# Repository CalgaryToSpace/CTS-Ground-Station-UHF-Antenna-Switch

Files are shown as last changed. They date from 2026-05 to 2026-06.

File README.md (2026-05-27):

# CTS-Ground-Station-UHF-Antenna-Switch

PCB and firmware for a ground station UHF antenna switch (between high-power uplink and low-noise downlink, via a single antenna).

This is a high-power UHF antenna switch PCB (for separate RX/TX paths), controlled with automatic TX sensing.

## Status

Rev 1 PCB works and is deployed at the CalgaryToSpace ground station as of 2026-05-26.

Rev 2 PCB is under development, though it is only a small incremental improvement over Rev 1. Main goal with Rev 2 is to improve the isolation performance.

## Render

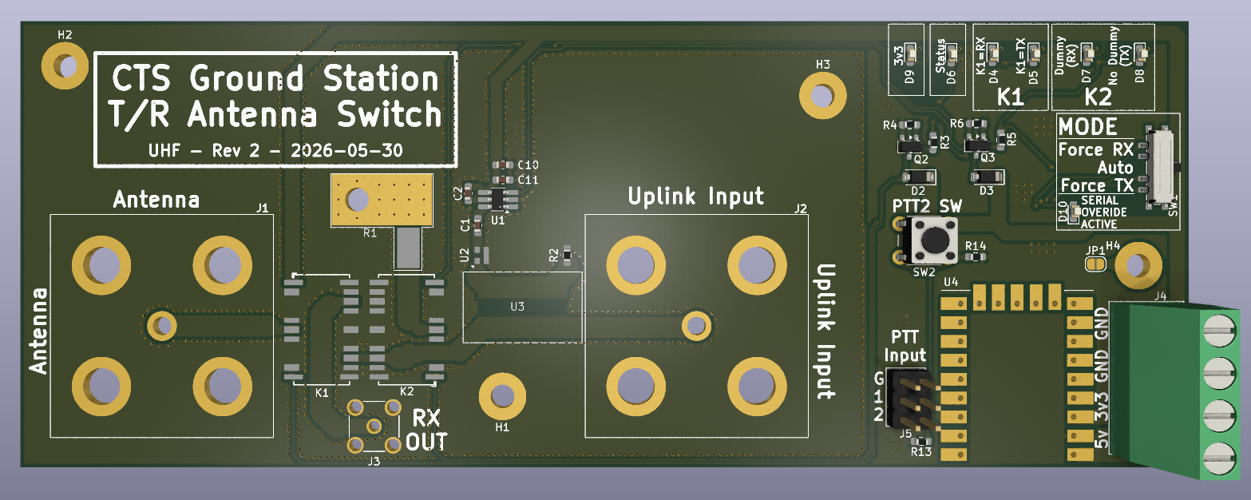
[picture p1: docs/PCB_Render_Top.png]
PCB Top Render


See the Releases for schematics, gerbers, and BOM.

## Features

* High Power: Supports TX power of >45 dBm (>30 W)
* Low insertion loss
* Automatic carrier sensing on the TX line (easy to deploy)
* Shunt-to-GND: Avoids damage to the transmitter by avoiding reflecting any power back on the TX port, in case of switching latency or failure. Dissipates as heat through a dummy load.
* LED indicators.
* Uses RF relays for switching. Simple design and minimal power supply requirements, compared to PIN Diode alternative approach.
* Logs via USB serial interface.
* Optional slide switch to override control modes.
* Optional control via USB serial interface overrides.

## Key Components

* RF Relay: `1462051-1` (`HF3-1` with 3V control, aka `HF3-51`)
* Dummy Load Resistor: `I100N50X4B`
* RF Attenuator (10 dB): `PAT1220-C-10DB-T5`
* RF Detector: `LTC5507ES6`
* Microcontroller: RP2040-Zero PCB

## License

* **Hardware Parts:** CERN Open Hardware Licence Version 2 - Permissive
* **Firmware:** Apache 2.0 License

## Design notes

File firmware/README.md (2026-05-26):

# CTS UHF RX/TX Switch Firmware

This firmware runs on the RP2040-Zero microcontroller board on the PCB.

## Building (Linux and macOS)

To build the firmware, follow these steps:

```bash
# Optionally, specify the Pico SDK path to your cloned Pico SDK (not recommended):
git clone https://github.com/raspberrypi/pico-sdk.git ~/pico-sdk
export PICO_SDK_PATH=~/pico-sdk

# If you skip the steps above (recommended to skip), cmake will automatically clone the Pico SDK.
cd firmware  # Navigate to the firmware directory of the repo.
mkdir build && cd build
cmake ..
make -j
```

## Flashing

1. Hold **BOOTSEL** on the RP2040-Zero while plugging it in. Or, hold **BOOTSEL** and press the reset button.
2. See that it mounts as a USB drive.
3. Drag `build/cts_uhf_rxtx_switch.uf2` onto it.
4. It'll reboot and run.

## Monitor via USB Serial

Open the USB serial port at 115200 baud:

```bash
# Linux
screen /dev/ttyACM0 115200

# macOS
screen /dev/tty.usbmodem* 115200
```

Press keys 0, 1, 2, 3 to set log level (0 = default and least verbose, 3 = most verbose).

To kill `screen`, press `Ctrl+A`, then nothing will appear to happen, then `k`, then `y` when prompted.

## IDE Support

After building, enable IDE support by creating a symbolic link to `compile_commands.json` in the build directory:

```bash
cd firmware
ln -s build/compile_commands.json compile_commands.json
```

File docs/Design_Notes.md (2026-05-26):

# Design Notes

## Checklist

* Unbroken ground plane under all RF.

## Dummy Load

* Use thin-film chip resistors. Standard thick-film resistors have too much parasitic inductance at UHF.
* Add a heatsink to the bottom of the board, potentially.
* Intended to operate only in small bursts, so thermal dissipation isn't as big of a deal.

### Test Notes

* SWR should be < 1.1:1 at 436 MHz for a good dummy load.
* Check for resonances. A peak in SWR somewhere means parasitic inductance or capacitance in the layout.

## Detector Chain

Input TX -> RF Coupler with PCB Traces -> Attenuator -> RF Detector -> Logic

* Input TX (rate up to 100W = 50 dBm for this assessment)
* RF Coupler with PCB Traces (50 dBm - 40 dB = 10 dBm)
    * Raw PCB traces running parallel to each other on the PCB act as an RF coupler.
    * Target -40 dB power transfer in coupler.
    * See the design doc for this coupler section specifically for more details.
* Attenuator (10 dB)
    * Part: PAT1220-C-10DB
* LTC5507 RF Detector
    * Supports -34 dBm to 14 dBm input.
    * At 50 dBm input, output power is approximately 10 dBm.
    * At 100 mW (20 dBm), output power is approximately -30 dBm. Should be possible to test with even just an SDR directly.

### Alternative Plan

<details summary="Click to expand">

Input TX -> RF Directional Coupler -> Attenuator -> RF Detector -> Logic

* Input TX (rate up to 100W = 50 dBm for this assessment)
* RF Directional Coupler (50 dBm down - 33 dB = 17 dBm)
    * Part: X4C09F1-30S
* Attenuator (10 dB)
    * Part: PAT1220-C-10DB
* LTC5507 RF Detector
    * Supports -34 dBm to 14 dBm input.

</details>

## RF Connectors

* SMA Connectors are [rated to >100W](https://electronics.stackexchange.com/a/74929), under ideal conditions and construction.
* N-Type connectors are better, where feasible. A [PCB-mount N-Type connector](https://www.mouser.ca/ProductDetail/Amphenol-RF/172234) is a good option.

* Alternatives considered:
    * https://www.digikey.ca/en/products/detail/huber-suhner-inc/92-N-50-0-6-111-NY/16806991
    * https://www.digikey.ca/en/products/detail/amphenol-rf/83-1R/80248

## Footprints

* RP2040-Zero footprint copied from https://github.com/dj505/RP2040-Zero-KiCAD (CERN Open Hardware License v2 - Permissive).

## Relay Switching Logic

* 2 relays.
    * K1: Picks between RX and TX.
    * K2: Adds a dummy loads to the TX line when in RX mode.

* Actions:
    * Nominally: K1 is in RX mode, and K2 is in Dummy mode.
    * When sense is detected: K1 switch to TX mode. Delay. K2 to TX mode.
    * When sense is done: K2 to Dummy mode. Delay. K1 to RX mode.

## Stackup, RF PCB Impedance

By using JLCPCB's default 1.6mm FR4 2-layer board, we can get a 50 ohm impedance with a large trace width, which is helpful for managing the high current.

For nearly the same price, we could have used a 4-layer board with a smaller trace width, but we intenionally take advantage of the thick trace width to carry more current.

Using [Digikey's PCB Trace Impedance Calculator](https://www.digikey.com/en/resources/conversion-calculators/conversion-calculator-pcb-trace-impedance):
* Input Target Impedance: 50 ohm
* Input Trace Thickness: 1 oz/ft^2
* Input Height (dielectric thickness): 1.58 mm
* Input Dielectric Constant: 4.5 ([Source](https://jlcpcb.com/capabilities/pcb-capabilities))
* Output Trace Width: 2.88mm

JLCPCB stackup: FR4 TG135 1.6mm 2-layer (default)

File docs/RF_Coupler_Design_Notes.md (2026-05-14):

# −40 dB Short-Section Microstrip Coupler at 436 MHz

## Chosen Configuration

| Parameter | Value |
|---|---|
| Trace width W | 2.9 mm |
| Gap S | ~2.5 mm |
| Coupled length L | 12 mm |

## Substrate

- FR-4, 1.6 mm thick, 2-layer
- εr = 4.5
- 1 oz copper (35 µm)
- Target Z0 = 50 Ω

## Design Goal

Sense 30–100 W transmit power at 436 MHz for an automatic PTT trigger, feeding an LTC5507ES6 RF power detector (input range −34 to +15 dBm).

## Coupling Math

Target coupling: **C = −40 dB**, so k = 10^(−40/20) = 0.01

For a short coupled section (L ≪ λ/4), coupling scales approximately as:

```
C(short) ≈ C(λ/4) × sin(βL)
```

where β = 2π / λg is the propagation constant in the medium.

**Effective wavelength on FR-4 (εr ≈ 4.5, εeff ≈ 3.35):**

```
λg = c / (f × √εeff) = (3×10⁸) / (436×10⁶ × √3.35) ≈ 376 mm
```

**Electrical length of the 12 mm section:**

```
βL = (2π / 376) × 12 ≈ 0.200 rad  (≈11.5°)
sin(βL) ≈ 0.199
```

To get final coupling of −40 dB (k = 0.01), the equivalent quarter-wave coupling would need to be:

```
k(λ/4) = 0.01 / 0.199 ≈ 0.0503  →  ≈ −26 dB
```

So the cross-section is sized for "moderate" coupling (~−26 dB at full λ/4), then truncated to 12 mm to attenuate the coupling down to −40 dB. The 2.5 mm gap achieves this moderate per-unit-length coupling on the given stackup.

## Power Budget

| TX Power | Main line | Coupled port (−40 dB) |
|---|---|---|
| 30 W | +44.8 dBm | +4.8 dBm |
| 100 W | +50.0 dBm | +10.0 dBm |

Add a **−10 dB chip attenuator** (0603/0805, ≥100 mW rated) between coupler and detector:

| TX Power | LTC5507 input |
|---|---|
| 30 W | −5.2 dBm |
| 100 W | 0.0 dBm |

Both well inside the LTC5507's log-linear range (−34 to +15 dBm).

## Signal Chain

```
TX in ──┬───────────────── TX out (to antenna)
        │
     [−40 dB coupler: 12 mm × 2.5 mm gap, W = 2.9 mm]
        │
     [−10 dB chip pad]
        │
     [LTC5507 RFIN]
        │
     [VOUT → comparator / MCU ADC → PTT logic]
```

The isolated port of the coupler is terminated in a 50 Ω SMD resistor (1206 thin-film, 0.5 W).

## Expected Performance

- Coupling: −40 dB ± ~2 dB (FR-4 εr variation)
- Insertion loss on through-line: < 0.1 dB
- Directivity: 6–10 dB (irrelevant for PTT sensing)
- Frequency response: essentially flat across the 70 cm band

## Tradeoffs Accepted

- No frequency selectivity (broadband coupling)
- Low directivity (forward and reverse couple nearly equally)
- Coupling rises with frequency below λ/4, but variation across a few MHz is negligible

## Layout Notes

- Solid ground plane on layer 2, no splits under the coupler
- Via fence along outer edges of the coupled section, ~5 mm pitch
- Feed lines: standard 50 Ω microstrip (~2.9 mm wide), continuous with coupler width
- Keep coupled-port output trace short; isolate detector area with ground pour and stitching vias
- Small RC lowpass (1 kΩ + 100 pF) on LTC5507 VOUT before the comparator to reject residual RF

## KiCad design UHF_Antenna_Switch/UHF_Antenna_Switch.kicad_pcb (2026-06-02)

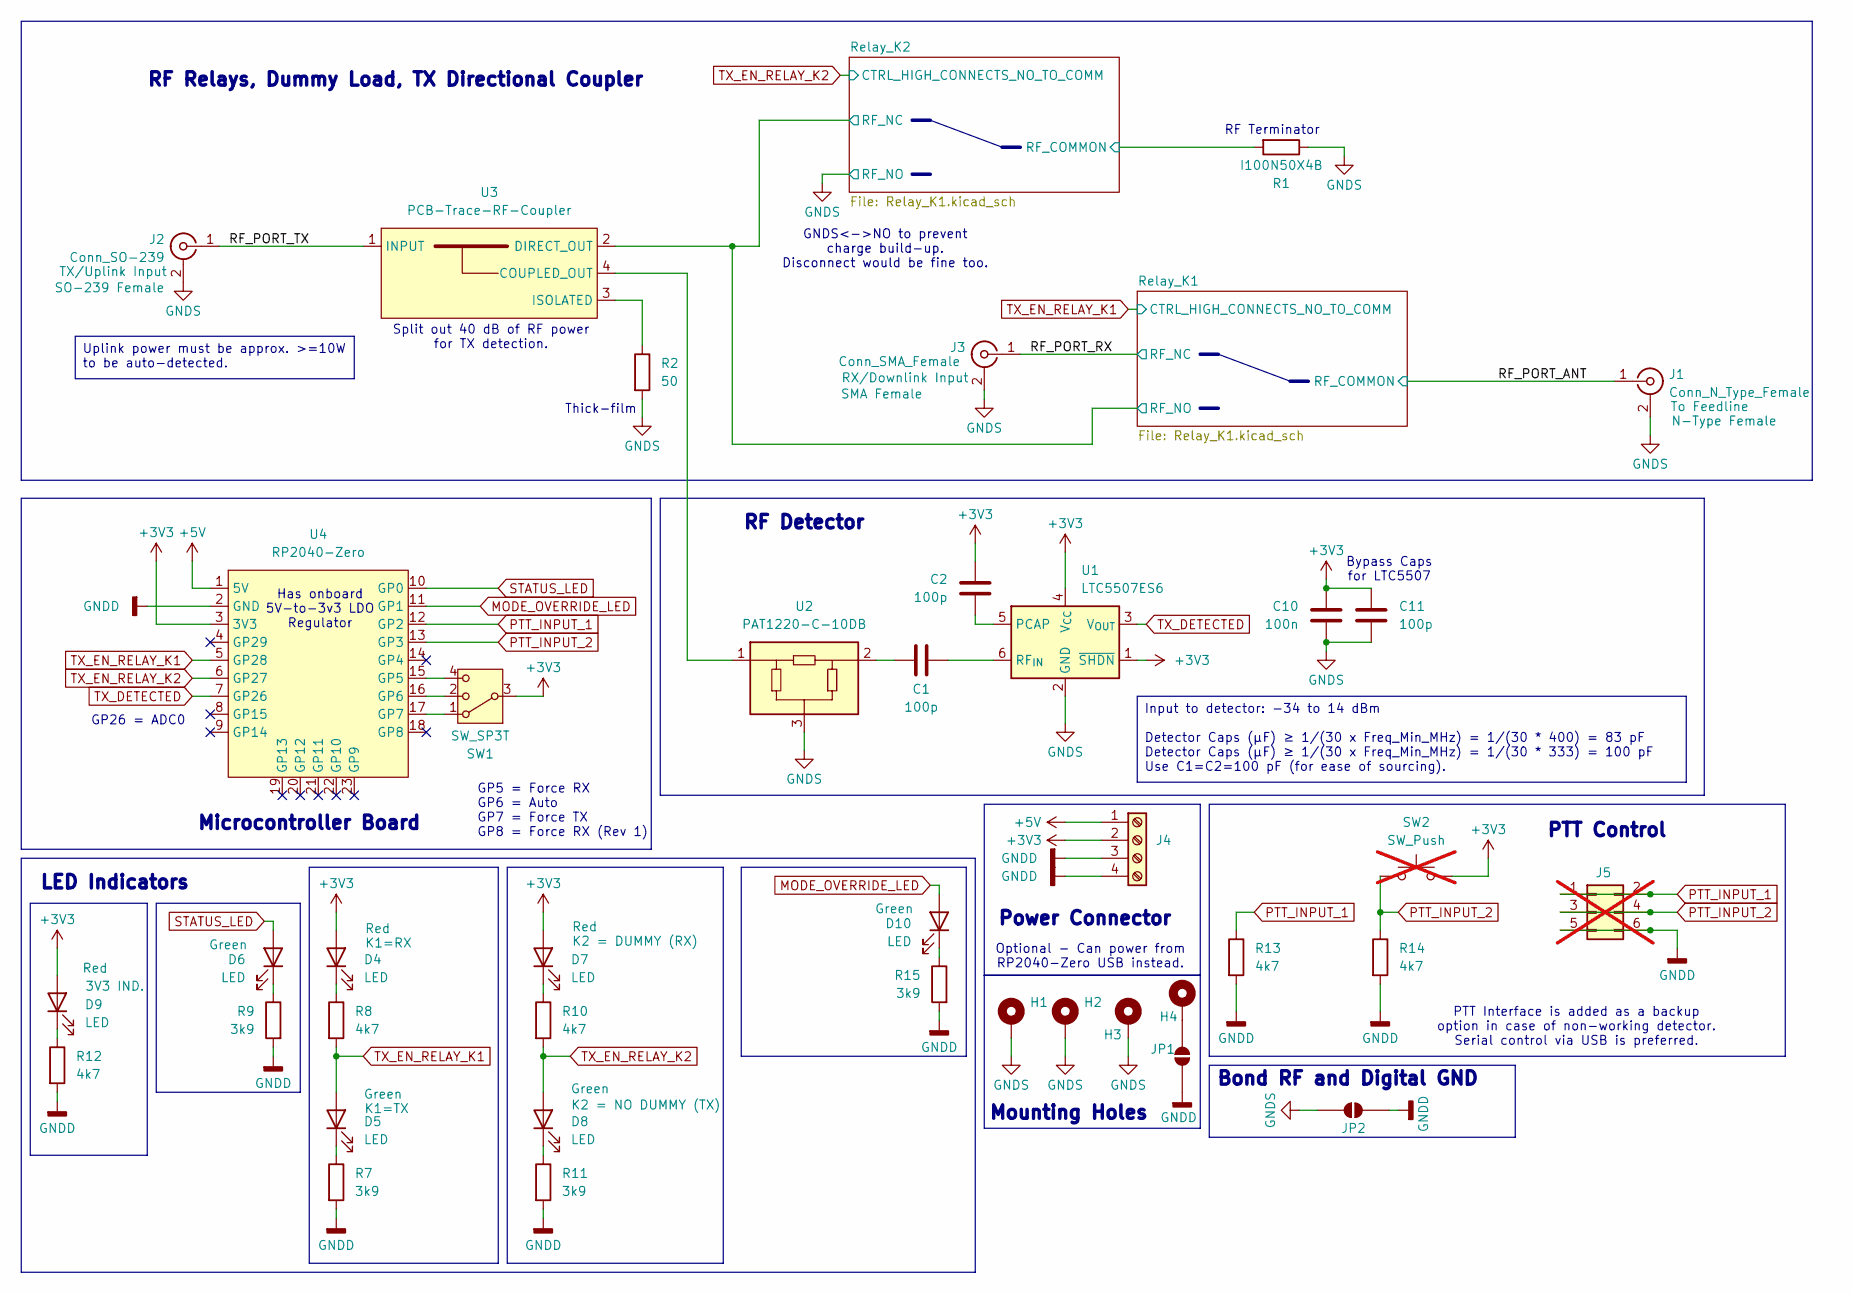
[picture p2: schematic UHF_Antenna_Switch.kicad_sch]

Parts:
C1, C2, C11: 100p; C_0603_1608Metric_Pad1.08x0.95mm_HandSolder
C10: 100n; C_0603_1608Metric_Pad1.08x0.95mm_HandSolder
D4, D5, D6, D7, D8, D9, D10: LED; LED_0603_1608Metric_Pad1.05x0.95mm_HandSolder
H1, H2, H3, H4: MountingHole_Pad; MountingHole_3.2mm_M3_Pad
J1: Conn_N_Type_Female; Amphenol N Jack 172234
J2: Conn_SO-239; Amphenol N Jack 172234
J3: Conn_SMA_Female; SMA_Amphenol_901-144_Vertical
J4: Screw_Terminal_01x04; TerminalBlock_Phoenix_MKDS-1,5-4-5.08_1x04_P5.08mm_Horizont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
J5: Conn_02x03_Odd_Even; PinHeader_2x03_P2.54mm_Vertical; not fitted
JP1, JP2: SolderJumper_2_Open; SolderJumper-2_P1.3mm_Open_RoundedPad1.0x1.5mm
R1: I100N50X4B; I100N50X4B-On-PCB
R2: 50; R_0603_1608Metric_Pad0.98x0.95mm_HandSolder
R7, R9, R11, R15: 3k9; R_0603_1608Metric_Pad0.98x0.95mm_HandSolder
R8, R10, R12, R13, R14: 4k7; R_0603_1608Metric_Pad0.98x0.95mm_HandSolder
SW1: SW_SP3T; SW_SP3T_PCM13
SW2: SW_Push; SW_PUSH_6mm_H4.3mm; not fitted
U1: LTC5507ES6; TSOT-23-6_HandSoldering
U2: PAT1220-C-10DB; RF_Attenuator_Susumu_PAT1220
U3: PCB-Trace-RF-Coupler
U4: RP2040-Zero; RP2040 Zero

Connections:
+3V3: C2.1, C10.1, C11.1, D4.2 (A), D7.2 (A), D9.2 (A), J4.2, SW1.3, SW2.2, U1.1 (~SHDN), U1.4 (V_{CC}), U4.3 (3V3); also elsewhere on the board
+5V: J4.1, U4.1 (5V)
/RF_PORT_ANT: J1.1 (In); also elsewhere on the board
/RF_PORT_RX: J3.1 (In); also elsewhere on the board
/RF_PORT_TX: J2.1 (In), U3.1 (INPUT)
/Relay_K1/RF_NO: U3.2 (DIRECT_OUT); also elsewhere on the board
/Relay_K2/RF_COMMON: R1.2; also elsewhere on the board
GNDD: J4.3, J4.4, J5.5, J5.6, JP1.1 (A), JP2.1 (A), R7.2, R9.2, R11.2, R12.2, R13.2, R14.2, R15.2, U4.2 (GND); also elsewhere on the board
GNDS: C10.2, C11.2, H1.1 (1_1), H2.1 (1_1), H3.1 (1_1), J1.2 (Ext), J2.2 (Ext), J3.2 (Ext), JP2.2 (B), R1.1, R2.2, U1.2 (GND), U2.3; also elsewhere on the board
MODE_OVERRIDE_LED: D10.2 (A), U4.11 (GP1)
unnamed: C1.1, U2.2
unnamed: D4.1 (K), R8.1
unnamed: D5.1 (K), R7.1
unnamed: D6.1 (K), R9.1
unnamed: D7.1 (K), R10.1
unnamed: D8.1 (K), R11.1
unnamed: D9.1 (K), R12.1
unnamed: D10.1 (K), R15.1
unnamed: H4.1 (1_1), JP1.2 (B)
unnamed: C2.2, U1.5 (PCAP)
unnamed: C1.2, U1.6 (RF_{IN})
unnamed: U2.1, U3.4 (COUPLED_OUT)
unnamed: R2.1, U3.3 (ISOLATED)
unnamed: SW1.4, U4.15 (GP5)
unnamed: SW1.2, U4.16 (GP6)
unnamed: SW1.1, U4.17 (GP7)
PTT_INPUT_1: J5.1, J5.2, R13.1, U4.12 (GP2)
PTT_INPUT_2: J5.3, J5.4, R14.1, SW2.1, U4.13 (GP3)
STATUS_LED: D6.2 (A), U4.10 (GP0)
TX_DETECTED: U1.3 (V_{OUT}), U4.7 (GP26)
TX_EN_RELAY_K1: D5.2 (A), R8.2, U4.5 (GP28); also elsewhere on the board
TX_EN_RELAY_K2: D8.2 (A), R10.2, U4.6 (GP27); also elsewhere on the board

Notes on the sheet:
Has onboard 5V-to-3v3 LDO Regulator
RF Relays, Dummy Load, TX Directional Coupler
Power Connector
Split out 40 dB of RF power for TX detection.
Mounting Holes
Thick-film
PTT Control
Optional - Can power from RP2040-Zero USB instead.
RF Detector
PTT Interface is added as a backup option in case of non-working detector. Serial control via USB is preferred.
GP26 = ADC0
GNDS<->NO to prevent charge build-up. Disconnect would be fine too.
GP5 = Force RX GP6 = Auto GP7 = Force TX GP8 = Force RX (Rev 1)
Bond RF and Digital GND
Bypass Caps for LTC5507
Microcontroller Board
LED Indicators
RF Terminator
Uplink power must be approx. >=10W to be auto-detected.
Input to detector: -34 to 14 dBm Detector Caps (µF) ≥ 1/(30 x Freq_Min_MHz) = 1/(30 * 400) = 83 pF Detector Caps (µF) ≥ 1/(30 x Freq_Min_MHz) = 1/(30 * 333) = 100 pF Use C1=C2=100 pF (for ease of sourcing).

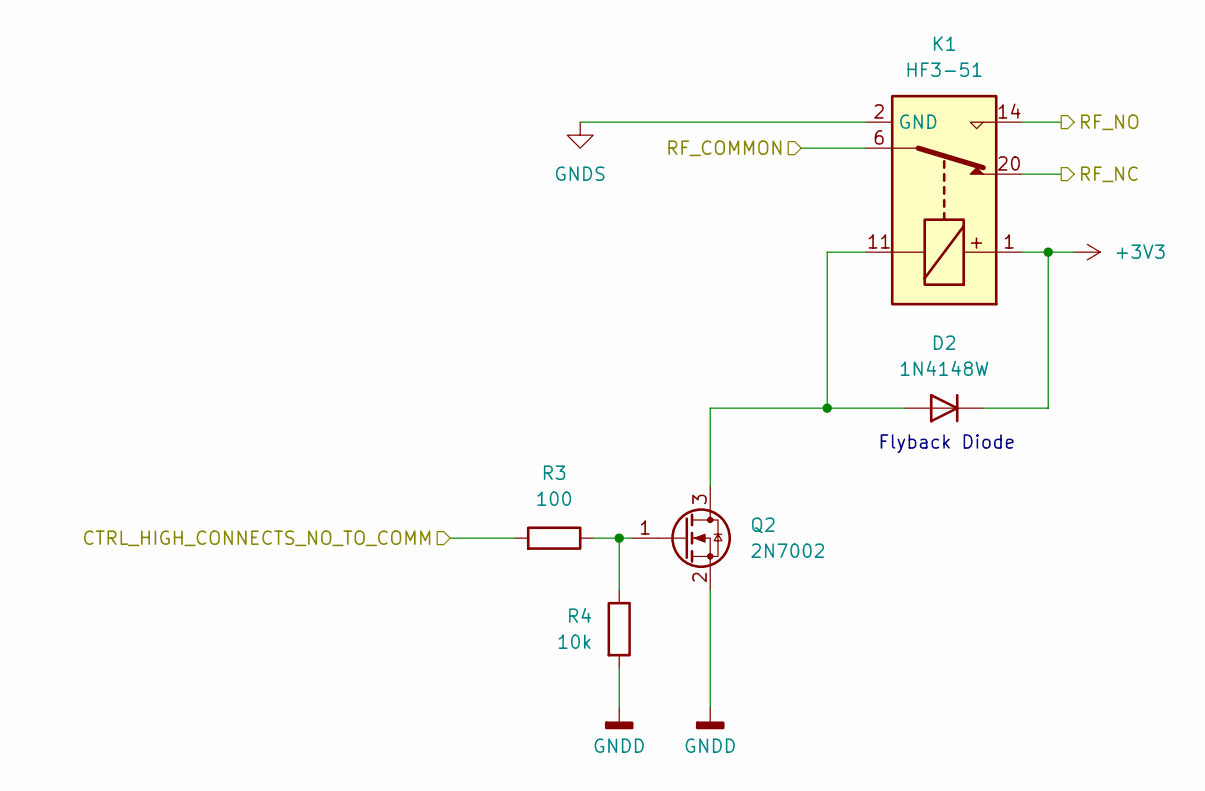
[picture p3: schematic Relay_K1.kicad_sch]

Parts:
D2: 1N4148W; D_SOD-123
K1: HF3-51; Relay_SPDT_AXICOM_HF3Series_50ohms_Pitch1.27mm
Q2: 2N7002; SOT-23
R3: 100; R_0603_1608Metric_Pad0.98x0.95mm_HandSolder
R4: 10k; R_0603_1608Metric_Pad0.98x0.95mm_HandSolder

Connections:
+3V3: D2.1 (K), K1.1; also elsewhere on the board
/RF_PORT_ANT: K1.6; also elsewhere on the board
/RF_PORT_RX: K1.20; also elsewhere on the board
/Relay_K1/RF_NO: K1.14; also elsewhere on the board
GNDD: Q2.2 (S), R4.2; also elsewhere on the board
GNDS: K1.2 (GND), K1.5 (GND), K1.7 (GND), K1.10 (GND), K1.12 (GND), K1.13 (GND), K1.15 (GND), K1.17 (GND), K1.19 (GND), K1.21 (GND), K1.22 (GND); also elsewhere on the board
unnamed: D2.2 (A), K1.11, Q2.3 (D)
unnamed: Q2.1 (G), R3.1, R4.1
TX_EN_RELAY_K1: R3.2; also elsewhere on the board

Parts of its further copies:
D3: 1N4148W; D_SOD-123
K2: HF3-51; Relay_SPDT_AXICOM_HF3Series_50ohms_Pitch1.27mm
Q3: 2N7002; SOT-23
R5: 100; R_0603_1608Metric_Pad0.98x0.95mm_HandSolder
R6: 10k; R_0603_1608Metric_Pad0.98x0.95mm_HandSolder

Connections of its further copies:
+3V3: D3.1 (K), K2.1; also elsewhere on the board
/Relay_K1/RF_NO: K2.20; also elsewhere on the board
/Relay_K2/RF_COMMON: K2.6; also elsewhere on the board
GNDD: Q3.2 (S), R6.2; also elsewhere on the board
GNDS: K2.2 (GND), K2.5 (GND), K2.7 (GND), K2.10 (GND), K2.12 (GND), K2.13 (GND), K2.14, K2.15 (GND), K2.17 (GND), K2.19 (GND), K2.21 (GND), K2.22 (GND); also elsewhere on the board
unnamed: D3.2 (A), K2.11, Q3.3 (D)
unnamed: Q3.1 (G), R5.1, R6.1
TX_EN_RELAY_K2: R5.2; also elsewhere on the board

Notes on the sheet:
Flyback Diode

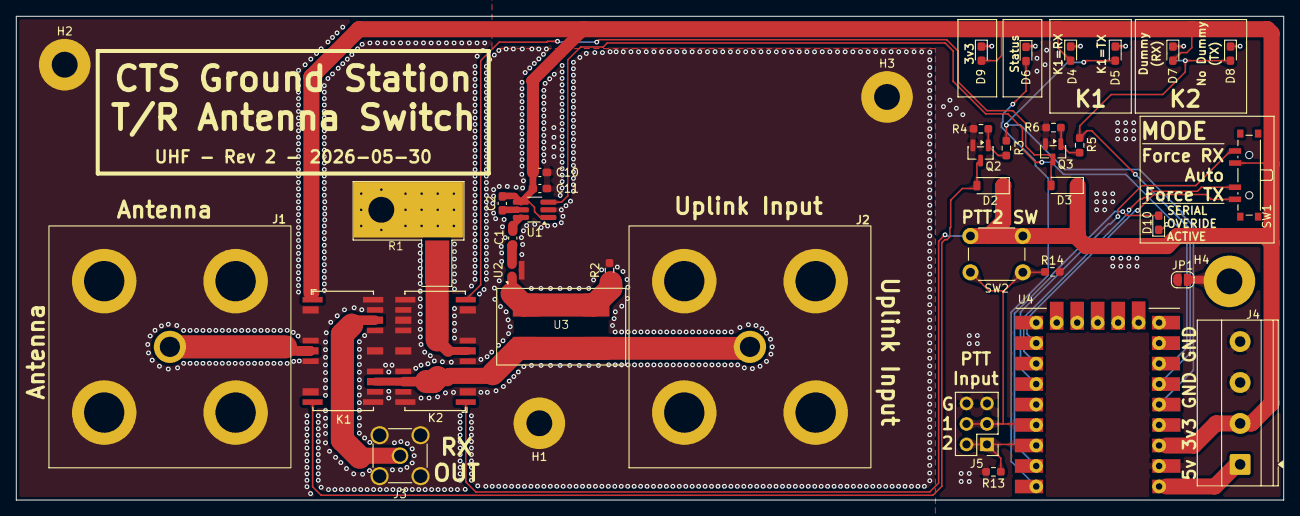
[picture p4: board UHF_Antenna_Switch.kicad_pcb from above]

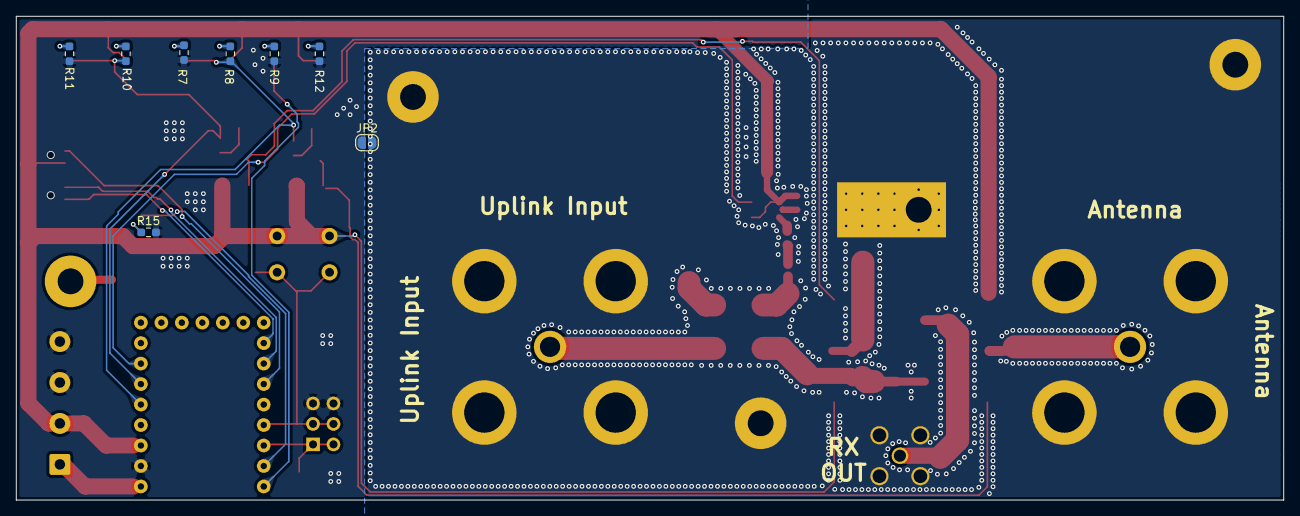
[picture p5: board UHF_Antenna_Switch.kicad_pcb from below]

Board: 2 copper layers, 157.2 x 60.0 mm, 49 parts (8 on the bottom side), 36 nets.

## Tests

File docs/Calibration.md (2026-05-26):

# Calibration

No calibration should be required. However, there are two configurable parameters hardcoded in the firmware which should be validated:

1. ADC detection threshold of the RF power sensing.
2. Relay activation/deactivation latency.

If you switch hardware components, this "calibration" procedure may be required. The values can easily be determined from datasheets.

## Preface

* This guide assumes you have a working board and have followed the `PCB_Test_Plan.md` guide.
* Be aware that damage may occur if followed improperly, or if the values are set incorrectly.

## Calibrating the RF Power Sense Threshold

This step pertains to the `TX_DETECT_THRESHOLD_RAW` value in firmware, which is used to auto-sense an attempt to TX and switch into TX mode.

1. Flash firmware and open serial terminal.
2. Connect a high-power RF transmitter of 30 dBm (1 watt) transmit power.
  * We use 1 watt as the minimum detection threshold. Calibrating for 1 watt will ensure that higher wattages also trigger the detector.
3. Activate max logging mode (press 3).
4. Observe the log messages showing the raw ADC value to get an **Idle** baseline (expected to be around 250mV to 300mV, or raw ADC values of 310-372).
5. Transit with RF (between 100ms to 500ms transmission is ideal).
6. Observe the log messages showing the raw ADC value to get the **active TX** value (expected to be >=400mV or raw ADC value 496).
7. Set `TX_DETECT_THRESHOLD_RAW` value to slightly below the ADC value observed during Step 6 (with TX), which should be comfortably above the value in Step 4 (idle).

The ADC on the RP2040 has a full-scale raw value of 4095 at 3.3v.

## Calibrating Relay Switching Threshold

This step pertains to the `RELAY_SWITCH_DELAY_MS` value in firmware, which is used to ensure the relays are switched in such a way that RF power is always sent to the Antenna or the RF Dummy load (or, very briefly, to both).

1. Assuming you trust the value in the relay datasheets, set `RELAY_SWITCH_DELAY_MS` to the maximum of the "max switching time" values.
  * If the datasheet gives separate Operate Time vs. Release Time, use the max value.
  * While it may be tempting to add a large margin (e.g., 2x to 10x) on this value for safety, avoid the temptation. Keeping the value very low is ideal because it minimizes the duration the transmit power is sent into the attenuator, and minimizes the duration the system has a 2:1 SWR (due to the dummy load and antenna effectively being in parallel).
2. If you don't trust the datasheet, devise an elaborate plan to send a voltage into the relay and measure it with a scope.

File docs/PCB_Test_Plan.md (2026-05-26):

# PCB Test Plan

## Basic Bring-Up

1. Check GND-to-3V3 and GND-to-5V rail resistance. Should be >30k.
2. Check for RF shorts to GND, especially at the high-power nodes through the relays. Probe each RF connector's center pin to its ground pins, and ensure open (Antenna and RX ports) or 50 ohms (TX/Uplink Input port).
3. Probe across R2 (50 ohm resistor). Should measure 25 ohms.
4. Check the unpowered default relay states. Antenna port to RX port should be NC. TX port to GND should be 50 ohms (already checked). TX port to R1 attenuator's top-side lead should be NC.

## Initial Flash and Naive Functionality Checks

1. Flash microcontroller with firmware.
2. Open a serial terminal on the virtual serial port of the MCU.
3. Set the log level to the max (press 3 on the keyboard).
4. Ensure LEDs are the expected states. That is, all indicate RX mode by default.
5. Try switching the switch control state. Ensure the lights update as expected.
  * For each state, use an ohm meter to check that the path through the center pins of the RF connectors are as expected.
    * In RX and Auto (thus RX), there should be <1 ohm from Antenna to RX and high impedance to TX.
    * In TX mode, there should be <1 ohm from Antenna to TX and high impedance from Antenna to RX.

## RF Validation

1. **Details coming:** Use a VNA to confirm impedance, SWR, and insertion loss.

## Functional Validation

1. Flash board.
2. Set log level to max.
3. Send >1 watt (30 dBm) RF power into the input RF port.
4. Observe that the logs show detection.
5. Observe that the LEDs switch to the TX state, with the K1 switching first to TX, and then the dummy load being removed second.

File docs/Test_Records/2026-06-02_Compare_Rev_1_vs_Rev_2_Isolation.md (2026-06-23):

# Compare Rev 1 vs. Rev 2 Isolation (2026-06-22)

After purchasing the Rev 2 PCB, but before purchasing components to assemble Rev 2, I wanted to use bare PCBs to confirm that Rev 2 has better isolation than Rev 1. Rev 2 improves on the Rev 1 design by using fencing vias around RF traces.

**Summary:** It's at least a bit better, but may require more parts to fully quantify how much better.

## Preparation

1. With both Rev 1 and Rev 2 boards, take a fresh board.
2. For each of R1, R2, and U2, short together all their terminals (within each component).
3. Run a jumper within K1 (RX/TX relay) to short together the Uplink Input port and the Antenna port.
    * Note: Pre-check done with RX Out port and Antenna port shorted.
    * Varied between Configuration 1 (K1=RX) and Configuration 2/3 (K1=TX).
4. Solder on SMA Female stubs for RX OUT port and Uplink Input port.
5. Set the NanoVNA range to 400 MHz to 500 MHz. Calibrate it.

## Results

Isolation values are the XXX values of "S21 LOGMAG 10dB/ XXX dB".

### Configuration 1: K1=RX, K1 bodge wire tight against PCB

This configuration is not of particular interest, but was tested nonetheless.

* K1=RX, Rev 1 isolation (RX Out to Uplink Input): -52 dB
* K1=RX, Rev 2 isolation (RX Out to Uplink Input): -59 dB

### Configuration 2: K1=TX, K1 bodge wire tight against PCB

* K1=TX, Rev 1 isolation (RX Out to Uplink Input): -26 dB
* K1=TX, Rev 2 isolation (RX Out to Uplink Input): -30 dB

### Configuration 3: K1=TX, K1 bodge wire pulled 2mm above PCB

* K1=TX, Rev 1 isolation (RX Out to Uplink Input): -39.0 dB
* K1=TX, Rev 2 isolation (RX Out to Uplink Input): -39.6 dB

## Conclusion

Isolation appears to be improved with Rev 2 vs. Rev 1, especially looking at Configuration 1 (-52 dB -> -59 dB) and Configuration 2 (-26 dB -> -30 dB). However, there's significant error in this approach: the bodge wire used in place of the RF relay leaks to the trace underneath it.

Configuration 3 shows little improvement in isolation (-39.0 dB -> -39.6 dB), though matching bodge wire geometries was challenging.

Testing with a real relay would help offer more confidence, as the measured isolation improvement differ significant between Configuration 2 and Configuration 3.

### Threats to Validity

* Antenna port is open instead of terminated. Would be terminated in real deployment.
* In Configuration 3, matching the bodge wire geometry (height above PCB) between Rev 1 and Rev 2 was difficult and more art than science. Small geometry changes yielded large isolation changes.

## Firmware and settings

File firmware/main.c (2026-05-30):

/*
 * CTS Ground Station RX/TX UHF Switch Firmware
 * Target: RP2040-Zero
 *
 * Responsibilities:
 *   - Drive K1 (RX/TX path) and K2 (dummy load) relays based on a selected mode.
 *   - Mode is set by a 1-hot 3-position switch: Auto / Force TX / Force RX.
 *   - In Auto mode, sense TX activity via an ADC-coupled detector.
 *   - Provide USB-CDC serial logging with runtime-selectable verbosity.
 *
 * Usage Notes:
 *   - Press keys 0/1/2/3 to set log level (0 = default and least verbose, 3 = most verbose).
 *   - Press 't'/'r'/'a' to force TX/RX/Auto, 's' to revert to the physical slide switch.
 *
 * Heartbeat (LOG_INFO, ~2.5 s):
 *   Heartbeat: state=<RX|TX> mode=<AUTO|FORCE_TX|FORCE_RX|INVALID> last_tx_ago_s=<sec.ms|never>
 *   last_tx_ago_s is the time since Auto mode last sensed TX, or "never"
 *   until the first detection.
 */

#include <stdio.h>
#include <stdint.h>
#include <stdbool.h>

// This build_info.h is generated by CMake at build time.
// Find it in `build/build_info.h`.
#include "build_info.h"

#include "pico/stdlib.h"
#include "pico/bootrom.h"
#include "pico/stdio_usb.h"
#include "hardware/adc.h"
#include "hardware/gpio.h"
#include "hardware/watchdog.h"

// ---------------------------------------------------------------------------
// Pin map
//
// Values are the x in the schematic's GPx pin labels.
// ---------------------------------------------------------------------------
#define PIN_STATUS_LED          0
#define PIN_SERIAL_OVERRIDE_LED 1

#define PIN_MODE_FORCE_RX_REV_2 5
#define PIN_MODE_AUTO           6
#define PIN_MODE_FORCE_TX       7
#define PIN_MODE_FORCE_RX_REV_1 8

#define PIN_TX_DETECT_ADC       26   // ADC0
#define ADC_TX_DETECT_CHANNEL   0

#define PIN_TX_EN_RELAY_K1      28   // RX/TX path relay   (LOW = RX path)
#define PIN_TX_EN_RELAY_K2      27   // Dummy load relay   (LOW = dummy applied)

// ---------------------------------------------------------------------------
// Tunables
// ---------------------------------------------------------------------------

// How long to wait before switching the relay after TX detection.
// Very critical that this is long enough for the relay to by fully switched before moving on.
// Datasheet (HF3-1): https://www.te.com/commerce/DocumentDelivery/DDEController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
static const uint32_t RELAY_SWITCH_DELAY_MS = 12;

// TX detector threshold. ADC reads 250-300mV nominally, >=400 mV when sensing TX (at >=-l6 dBm).
// 3.3 V reference, 12-bit ADC -> 1 LSB = 0.806 mV.
// Threshold: 400 mV -> 496 raw counts.
// Datasheet (LTC5507ES6): https://www.analog.com/media/en/technical-documentation/data-sheets/5507f.pdf
static const uint32_t TX_DETECT_THRESHOLD_RAW = 496;

// How often Auto-mode samples the detector.
static const uint32_t AUTO_POLL_INTERVAL_US = 100;

// Status LED heartbeat behaviour at idle (in RX state).
static const uint32_t HEARTBEAT_PERIOD_MS = 1000;
static const uint32_t HEARTBEAT_ON_TIME_MS = 100;

// At LOG_TRACE, dump ADC value at this interval (don't flood the link).
static const uint32_t ADC_TRACE_INTERVAL_MS = 100;

// At LOG_INFO or higher, print a heartbeat message.
static const uint32_t INFO_HEARTBEAT_MESSAGE_INTERVAL_MS = 2500;

// ---------------------------------------------------------------------------
// Logging
// ---------------------------------------------------------------------------
typedef enum {
    LOG_ALWAYS = 0,   // Boot banner + critical only
    LOG_INFO   = 1,   // Mode/state transitions
    LOG_DEBUG  = 2,   // + periodic state
    LOG_TRACE  = 3,   // + continuous ADC stream
} log_level_t;

static volatile log_level_t g_log_level = LOG_ALWAYS;

static const char *log_level_name(log_level_t level) {
    switch (level) {
        case LOG_ALWAYS:  return "ALWAYS";
        case LOG_INFO:  return " INFO ";
        case LOG_DEBUG: return "DEBUG ";
        case LOG_TRACE: return "TRACE ";
    }
    return "UNKNOWN";
}

#define LOG(level, fmt, ...) \
    do { \
        if (g_log_level >= (level)) { \
            printf("[%lu] [%s] " fmt "\n", (unsigned long)to_ms_since_boot(get_absolute_time()), log_level_name(level), ##__VA_ARGS__); \
        } \
    } while (0)

// ---------------------------------------------------------------------------
// Mode + RF state
// ---------------------------------------------------------------------------
typedef enum {
    MODE_AUTO,
    MODE_FORCE_TX,
    MODE_FORCE_RX,
    MODE_INVALID,    // No switch position asserted (shouldn't happen with 1-hot).
} mode_t;

// MODE_INVALID means "no serial override; use the physical switch".
static volatile mode_t g_serial_mode_override = MODE_INVALID;

typedef enum {
    RF_RX,           // K1 = RX path,  K2 = dummy load on TX line.
    RF_TX,           // K1 = TX path,  K2 = TX line passthrough.
} rf_state_t;

static const char *mode_name(mode_t m) {
    switch (m) {
        case MODE_AUTO:     return "AUTO";
        case MODE_FORCE_TX: return "FORCE_TX";
        case MODE_FORCE_RX: return "FORCE_RX";
        default:            return "INVALID";
    }
}

static const char *mode_name_sourced(mode_t m, bool from_serial) {
    if (from_serial) {
        switch (m) {
            case MODE_AUTO:     return "AUTO_BY_SERIAL";
            case MODE_FORCE_TX: return "FORCE_TX_BY_SERIAL";
            case MODE_FORCE_RX: return "FORCE_RX_BY_SERIAL";
            default:            return "INVALID";
        }
    } else {
        switch (m) {
            case MODE_AUTO:     return "AUTO_BY_SWITCH";
            case MODE_FORCE_TX: return "FORCE_TX_BY_SWITCH";
            case MODE_FORCE_RX: return "FORCE_RX_BY_SWITCH";
            default:            return "INVALID";
        }
    }
}

static const char *rf_state_name(rf_state_t s) {
    return (s == RF_TX) ? "TX" : "RX";
}

// ---------------------------------------------------------------------------
// GPIO / ADC helpers
// ---------------------------------------------------------------------------
static void relays_set(rf_state_t state) {
    // K1 LOW = RX path,  K1 HIGH = TX path.
    // K2 LOW = dummy applied,  K2 HIGH = TX passthrough.
    // Sequencing: when entering TX, flip K1 first then K2 (after delay).
    //             when entering RX, flip K2 first then K1 (after delay).
    if (state == RF_TX) {
        gpio_put(PIN_TX_EN_RELAY_K1, 1);
        sleep_ms(RELAY_SWITCH_DELAY_MS);
        gpio_put(PIN_TX_EN_RELAY_K2, 1);
        sleep_ms(RELAY_SWITCH_DELAY_MS); // Critical: Wait for the second relay to stabilize too!
    } else {
        gpio_put(PIN_TX_EN_RELAY_K2, 0);
        sleep_ms(RELAY_SWITCH_DELAY_MS);
        gpio_put(PIN_TX_EN_RELAY_K1, 0);
        sleep_ms(RELAY_SWITCH_DELAY_MS); // Critical: Wait for the second relay to stabilize too!
    }
}

/// Read the 1-hot SP3T switch and return the corresponding mode.
static mode_t read_mode_switch(void) {
    // 1-hot, active-high (pull-downs hold unselected pins low).
    const bool a = gpio_get(PIN_MODE_AUTO);
    const bool t = gpio_get(PIN_MODE_FORCE_TX);
    const bool rx_rev1 = gpio_get(PIN_MODE_FORCE_RX_REV_1);
    const bool rx_rev2 = gpio_get(PIN_MODE_FORCE_RX_REV_2);

    if (a && !t && !rx_rev1 && !rx_rev2) return MODE_AUTO;
    if (!a && t && !rx_rev1 && !rx_rev2) return MODE_FORCE_TX;
    if (!a && !t && (rx_rev1 || rx_rev2)) return MODE_FORCE_RX;
    return MODE_INVALID;
}

/// Read the ADC input for TX detect. Returns the raw ADC value (0-4095).
///
/// Averages 8 samples.
static uint16_t adc_read_tx_detect(void) {
    adc_select_input(ADC_TX_DETECT_CHANNEL);

    uint sum = 0;
    for (int i = 0; i < 8; i++) {
        sum += adc_read();
    }
    return sum / 8;
}

// Returns true if TX sensed.
// Kept as a single function so it can later be swapped for a PTT GPIO read
// without touching the state machine, if desired.
static bool tx_sensed(void) {
    const uint16_t raw = adc_read_tx_detect();

    if (raw >= TX_DETECT_THRESHOLD_RAW) {
        LOG(LOG_DEBUG, "TX Sensed! tx_sensed: raw=%d", raw);
        return true;
    }

    return false;
}

static void print_help(void) {
    LOG(LOG_ALWAYS, "================= HELP ========================");
    LOG(LOG_ALWAYS, "Send '0'/'1'/'2'/'3' to set log level (default = 0)");
    LOG(LOG_ALWAYS, "  0 = nearly none, 1 = info, 2 = debug, 3 = trace");
    LOG(LOG_ALWAYS, "Send 't'/'r'/'a' to force TX/RX/Auto, 's' to go back to using the slide switch (default = slide switch)");
    LOG(LOG_ALWAYS, "Send 'f' to reboot into flash bootloader mode");
    LOG(LOG_ALWAYS, "Send 'x' to reboot");
    LOG(LOG_ALWAYS, "Send 'h' to print this help message");
    LOG(LOG_ALWAYS, "===============================================");
    LOG(LOG_ALWAYS, "Build: " BUILD_TIMESTAMP " git=" GIT_COMMIT);
    LOG(LOG_ALWAYS, "===============================================");
}

/// Parse single-character serial input commands and execute/handle them.
static void poll_serial_input(void) {
    const int c = getchar_timeout_us(0);
    if (c == PICO_ERROR_TIMEOUT) return;

    if (c >= '0' && c <= '3') {
        log_level_t new_level = (log_level_t)(c - '0');
        g_log_level = new_level;
        LOG(LOG_ALWAYS, "Log level set to %d", new_level);
    } else if (c == 't') {
        g_serial_mode_override = MODE_FORCE_TX;
        LOG(LOG_ALWAYS, "Serial override -> FORCE_TX");
    } else if (c == 'r') {
        g_serial_mode_override = MODE_FORCE_RX;
        LOG(LOG_ALWAYS, "Serial override -> FORCE_RX");
    } else if (c == 'a') {
        g_serial_mode_override = MODE_AUTO;
        LOG(LOG_ALWAYS, "Serial override -> AUTO");
    } else if (c == 's') {
        g_serial_mode_override = MODE_INVALID;
        LOG(LOG_ALWAYS, "Serial override cleared, using slide switch");
    } else if (c == 'h') {
        print_help();
    } else if (c == 'f') {
        LOG(LOG_ALWAYS, "Rebooting into flash bootloader mode...");
        sleep_ms(1000);
        reset_usb_boot(0, 0);
    } else if (c == 'x') {
        LOG(LOG_ALWAYS, "Rebooting...");
        sleep_ms(1000);
        watchdog_reboot(0, 0, 0);  // Triggers an immediate watchdog reset -> firmware restart.
    }
}

// ---------------------------------------------------------------------------
// Setup
// ---------------------------------------------------------------------------
static void setup_gpio(void) {
    gpio_init(PIN_STATUS_LED);
    gpio_set_dir(PIN_STATUS_LED, GPIO_OUT);
    gpio_put(PIN_STATUS_LED, 0);

    gpio_init(PIN_SERIAL_OVERRIDE_LED);
    gpio_set_dir(PIN_SERIAL_OVERRIDE_LED, GPIO_OUT);
    gpio_put(PIN_SERIAL_OVERRIDE_LED, 0);

    // Mode switch inputs with internal pull-downs.
    const uint mode_pins[] = { PIN_MODE_AUTO, PIN_MODE_FORCE_TX, PIN_MODE_FORCE_RX_REV_1, PIN_MODE_FORCE_RX_REV_2 };
    for (size_t i = 0; i < sizeof(mode_pins) / sizeof(mode_pins[0]); i++) {
        gpio_init(mode_pins[i]);
        gpio_set_dir(mode_pins[i], GPIO_IN);
        gpio_pull_down(mode_pins[i]);
    }

    // Relay outputs, default LOW (= RX + dummy applied = safe nominal state).
    gpio_init(PIN_TX_EN_RELAY_K1);
    gpio_set_dir(PIN_TX_EN_RELAY_K1, GPIO_OUT);
    gpio_put(PIN_TX_EN_RELAY_K1, 0);

    gpio_init(PIN_TX_EN_RELAY_K2);
    gpio_set_dir(PIN_TX_EN_RELAY_K2, GPIO_OUT);
    gpio_put(PIN_TX_EN_RELAY_K2, 0);
}

static void setup_adc(void) {
    adc_init();
    adc_gpio_init(PIN_TX_DETECT_ADC);
    adc_select_input(ADC_TX_DETECT_CHANNEL);
}

bool status_led_state = false;
static void set_status_led(bool state) {
    if (state == status_led_state) {
        return;
    }

    LOG(LOG_DEBUG, "set_status_led: %d -> %d", status_led_state, state);

    status_led_state = state;
    gpio_put(PIN_STATUS_LED, state);
}

// ---------------------------------------------------------------------------
// Main loop
// ---------------------------------------------------------------------------
int main(void) {
    stdio_init_all();
    setup_gpio();
    setup_adc();

    rf_state_t  rf_state              = RF_RX;
    mode_t      last_mode             = MODE_INVALID;
    bool        last_serial_override_active = false;
    uint32_t    last_adc_value_trace_time  = 0;
    uint32_t    last_info_heartbeat_time = 0;
    // Uptime (ms) when Auto mode last sensed TX. 0 = never sensed.
    // Reported by the heartbeat as seconds-since so a ground-station
    // host can confirm the switch actually saw its uplink burst.
    uint32_t    last_tx_detect_ms = 0;
    bool last_cdc_connected = false;
    uint32_t last_cdc_connected_check_time = 0;

    // Force initial state on the relays.
    relays_set(RF_RX);

    // [WATCHDOG] Detect if we woke from a watchdog reset and log it.
    const bool did_watchdog_cause_reboot = watchdog_caused_reboot();

    // [WATCHDOG] Enable. Timeout is 5000 ms.
    // pause_on_debug=true freezes the counter while a debugger is halted.
    watchdog_enable(5000, true);
    LOG(LOG_ALWAYS, "Watchdog enabled (5000 ms timeout)");

    while (true) {
        poll_serial_input();

        watchdog_update();  // [WATCHDOG] Feed dog. Must run < every 5000 ms.

        const uint32_t now = to_ms_since_boot(get_absolute_time());
        const bool   serial_override_active = (g_serial_mode_override != MODE_INVALID);
        const mode_t desired_mode     = serial_override_active
                                        ? g_serial_mode_override
                                        : read_mode_switch();

        // Check for USB CDC connection status periodically.
        // If it's a new connection, log a message and print help.
        if (now - last_cdc_connected_check_time > 750) {
            const bool cdc_connected = stdio_usb_connected();
            if (cdc_connected && !last_cdc_connected) {
                sleep_ms(100); // Brief settling time for the CDC link to stabilize.
                LOG(LOG_ALWAYS, "===============================================");
                LOG(LOG_ALWAYS, "CTS UHF RX/TX Switch connected to USB...");
                LOG(LOG_ALWAYS, "Build: " BUILD_TIMESTAMP " git=" GIT_COMMIT);
                if (did_watchdog_cause_reboot) {
                    LOG(LOG_ALWAYS, "*** LAST REBOOT: WATCHDOG RESET DETECTED ***");
                }
                LOG(LOG_ALWAYS, "===============================================");
                print_help();
            }
            last_cdc_connected = cdc_connected;
            last_cdc_connected_check_time = now;
        }

        if ((desired_mode != last_mode) || (serial_override_active != last_serial_override_active)) {
            gpio_put(PIN_SERIAL_OVERRIDE_LED, serial_override_active);
            LOG(LOG_INFO, "Mode -> %s", mode_name_sourced(desired_mode, serial_override_active));
            last_mode             = desired_mode;
            last_serial_override_active = serial_override_active;
        }

        // Decide desired RF state from mode.
        rf_state_t desired_rf_state = rf_state;
        switch (desired_mode) {
            case MODE_FORCE_TX:
                desired_rf_state = RF_TX;
                break;
            case MODE_FORCE_RX:
                desired_rf_state = RF_RX;
                break;
            case MODE_AUTO: {
                const bool sensed = tx_sensed();
                desired_rf_state = sensed ? RF_TX : RF_RX;
                // Stamp every poll that crosses the threshold so the
                // heartbeat's "seconds ago" tracks the most recent
                // detection. Only Auto mode counts as an auto-detect;
                // Force TX deliberately doesn't update this.
                if (sensed) {
                    last_tx_detect_ms = now;
                }
                break;
            }
            case MODE_INVALID:
            default:
                // Safe fallback: drop to RX.
                {
                    desired_rf_state = RF_RX;
                    LOG(LOG_INFO, "Invalid mode (>1-hot) -> %s. Fallback to RX.", mode_name(desired_mode));
                }
                break;
        }

        if (desired_rf_state != rf_state) {
            LOG(LOG_DEBUG, "Starting RF %s -> %s", rf_state_name(rf_state), rf_state_name(desired_rf_state));
            relays_set(desired_rf_state);
            LOG(LOG_INFO, "Done RF %s -> %s", rf_state_name(rf_state), rf_state_name(desired_rf_state));
            rf_state = desired_rf_state;
        }

        // Trace-level continuous ADC dump (rate-limited so logs stay readable).
        if (g_log_level >= LOG_TRACE && (now - last_adc_value_trace_time) >= ADC_TRACE_INTERVAL_MS) {
            uint16_t raw = adc_read_tx_detect();
            uint32_t mV  = (raw * 3300u) / 4095u;
            LOG(
                LOG_TRACE,
                "ADC: now_ms=%lu raw=%u mV=%lu state=%s mode=%s",
                (unsigned long)now, raw, (unsigned long)mV,
                rf_state_name(rf_state), mode_name_sourced(desired_mode, serial_override_active)
            );
            last_adc_value_trace_time = now;
        }

        // Info-level heartbeat.
        if (g_log_level >= LOG_INFO && (now - last_info_heartbeat_time >= INFO_HEARTBEAT_MESSAGE_INTERVAL_MS)) {
            if (last_tx_detect_ms == 0) {
                LOG(
                    LOG_INFO,
                    "Heartbeat: log_level=%d state=%s mode=%s last_tx_ago_s=never",
                    g_log_level,
                    rf_state_name(rf_state),
                    mode_name_sourced(desired_mode, serial_override_active)
                );
            } else {
                const uint32_t age_ms = now - last_tx_detect_ms;
                LOG(
                    LOG_INFO,
                    "Heartbeat: log_level=%d state=%s mode=%s last_tx_ago_s=%lu.%03lu",
                    g_log_level,
                    rf_state_name(rf_state),
                    mode_name_sourced(desired_mode, serial_override_active),
                    (unsigned long)(age_ms / 1000u),
                    (unsigned long)(age_ms % 1000u)
                );
            }

            last_info_heartbeat_time = now;
        }

        // Heartbeat LED: solid when TX, short-pulse blinking when RX.
        if (rf_state == RF_TX) {
            set_status_led(true);
        }
        else {
            set_status_led((now % HEARTBEAT_PERIOD_MS) < HEARTBEAT_ON_TIME_MS);
        }

        sleep_us(AUTO_POLL_INTERVAL_US);
    }
}

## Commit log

2026-05-11 Add empty KiCAD project
    [UHF_Antenna_Switch.kicad_pcb, UHF_Antenna_Switch.kicad_sch]
2026-05-11 Schematic: Draw relays and dummy load
    [UHF_Antenna_Switch.kicad_sch]
2026-05-12 Draw relay buffers and detector
    [Relay_K1.kicad_sch, UHF_Antenna_Switch.kicad_sch]
2026-05-12 Schematic: Add RP2040 microcontroller and LEDs
    [UHF_Antenna_Switch.kicad_sch]
2026-05-12 Assign most footprints
    [Relay_K1.kicad_sch, UHF_Antenna_Switch.kicad_pcb, UHF_Antenna_Switch.kicad_sch]
2026-05-12 Add N-Type PCB connector footprint
    [UHF_Antenna_Switch.kicad_pcb, UHF_Antenna_Switch.kicad_sch]
2026-05-12 docs: Add note about footprints
2026-05-12 Add 3V3 power connector
    [UHF_Antenna_Switch.kicad_pcb, UHF_Antenna_Switch.kicad_sch]
2026-05-12 Add preliminary footprint to directional coupler and begin layout
    [Relay_K1.kicad_sch, UHF_Antenna_Switch.kicad_pcb, UHF_Antenna_Switch.kicad_sch]
2026-05-12 Rename X4C09F1-30S footprint with no space
    [UHF_Antenna_Switch.kicad_sch]
2026-05-12 Configure net classes and trace widths
    [Relay_K1.kicad_sch, UHF_Antenna_Switch.kicad_pcb, UHF_Antenna_Switch.kicad_sch]
2026-05-13 Complete initial positioning of components (no routing)
    [UHF_Antenna_Switch.kicad_pcb, UHF_Antenna_Switch.kicad_sch]
2026-05-13 Schematic: Add PTT switches, PTT header, 5V power screw
    [UHF_Antenna_Switch.kicad_pcb, UHF_Antenna_Switch.kicad_sch]
2026-05-13 Footprint: Draw RF coupler with microstrip
    [UHF_Antenna_Switch.kicad_pcb, UHF_Antenna_Switch.kicad_sch]
2026-05-13 PCB: Route RF components
    [UHF_Antenna_Switch.kicad_pcb]
2026-05-14 PCB: Route digital components
    [Relay_K1.kicad_sch, UHF_Antenna_Switch.kicad_pcb, UHF_Antenna_Switch.kicad_sch]
2026-05-14 PCB: Add many labels
    [Relay_K1.kicad_sch, UHF_Antenna_Switch.kicad_pcb]
2026-05-14 PCB: Fix keepout region on Trace RF Coupler
    [UHF_Antenna_Switch.kicad_pcb]
2026-05-14 PCB: Resolve DRC issues
    [UHF_Antenna_Switch.kicad_pcb, UHF_Antenna_Switch.kicad_sch]
2026-05-14 PCB: Add 4th mounting hole
    [Relay_K1.kicad_sch, UHF_Antenna_Switch.kicad_pcb, UHF_Antenna_Switch.kicad_sch]
2026-05-14 Bond RF and Digital GNDs
    [UHF_Antenna_Switch.kicad_pcb, UHF_Antenna_Switch.kicad_sch]
2026-05-14 Export rc1 gerber
    [UHF_Antenna_Switch.kicad_pcb]
2026-05-14 Resave after exporting Rev 1 gerber
    [UHF_Antenna_Switch.kicad_pcb]
2026-05-14 docs: Add PCB Render to repo
2026-05-14 build: Auto-download the Pico SDK on build
2026-05-15 fix: Bad RF detection threshold
    [main.c]
2026-05-23 docs: Add Calibration.md guide
2026-05-23 docs: Add basic PCB Test Plan
2026-05-26 report seconds since last TX detection in the heartbeat (#6)
    Track the uptime in milliseconds whenever Auto mode senses TX, and add
    it to the info heartbeat as last_tx_ago_s (the time since the most
    recent detection, or "never" until the first one). The existing
    state and mode fields are unchanged, so anything already reading the
    heartbeat keeps working.
    This lets a ground-station host confirm that the switch actually saw
    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
2026-05-26 config: Set relay latency to 12ms
2026-05-27 fix(pcb): Jagged gnd plane shard
    [UHF_Antenna_Switch.kicad_pcb]
2026-05-27 chore(pcb): Add LED colors, update LED resistor values
    [UHF_Antenna_Switch.kicad_pcb, UHF_Antenna_Switch.kicad_sch]
2026-05-27 fix(pcb): Add silkscreen labels for RF ports on backside
    [UHF_Antenna_Switch.kicad_pcb]
2026-05-27 fix(pcb): Make attenuator gnd pad solid
    [UHF_Antenna_Switch.kicad_pcb, UHF_Antenna_Switch.kicad_sch]
2026-05-27 fix(pcb): Add vias for heat dissipation under dummy load attenuator
    [UHF_Antenna_Switch.kicad_pcb, UHF_Antenna_Switch.kicad_sch]
2026-05-27 feat(fw): Add help menu, reboot commands
    [main.c]
2026-05-27 tiny(pcb): Move K1 down
    [UHF_Antenna_Switch.kicad_sch]
2026-05-27 chore(pcb): Minor layout tweaks in RF area
    [UHF_Antenna_Switch.kicad_pcb, UHF_Antenna_Switch.kicad_sch]
2026-05-27 feat(pcb): Add tons of fencing vias
    [UHF_Antenna_Switch.kicad_pcb]
2026-05-30 feat: Add Serial Override LED indicator
    [UHF_Antenna_Switch.kicad_pcb, UHF_Antenna_Switch.kicad_sch]
2026-05-30 fix(pcb): Swap order of mode switch items
    [UHF_Antenna_Switch.kicad_pcb, UHF_Antenna_Switch.kicad_sch]
2026-05-30 feat(fw): Add serial override LED and Rev 2 switch support
2026-05-30 feat(pcb): Finish Rev 2 render, exports
    [Relay_K1.kicad_sch, UHF_Antenna_Switch.kicad_pcb, UHF_Antenna_Switch.kicad_sch]
2026-06-02 fix(pcb): DRC rule about intentional shorted nets in RF coupler
    [UHF_Antenna_Switch.kicad_pcb]
